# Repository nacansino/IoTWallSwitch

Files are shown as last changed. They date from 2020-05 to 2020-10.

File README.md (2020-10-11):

# IoTWallSwitch
An open-source IoT Wall Switch based on ESP device. I based this project on Xoseperez's [espurna-board project](https://github.com/xoseperez/espurna-board).

I aim this project to be a foundation of many small projects that ran on tap power supply.

## Block Diagram
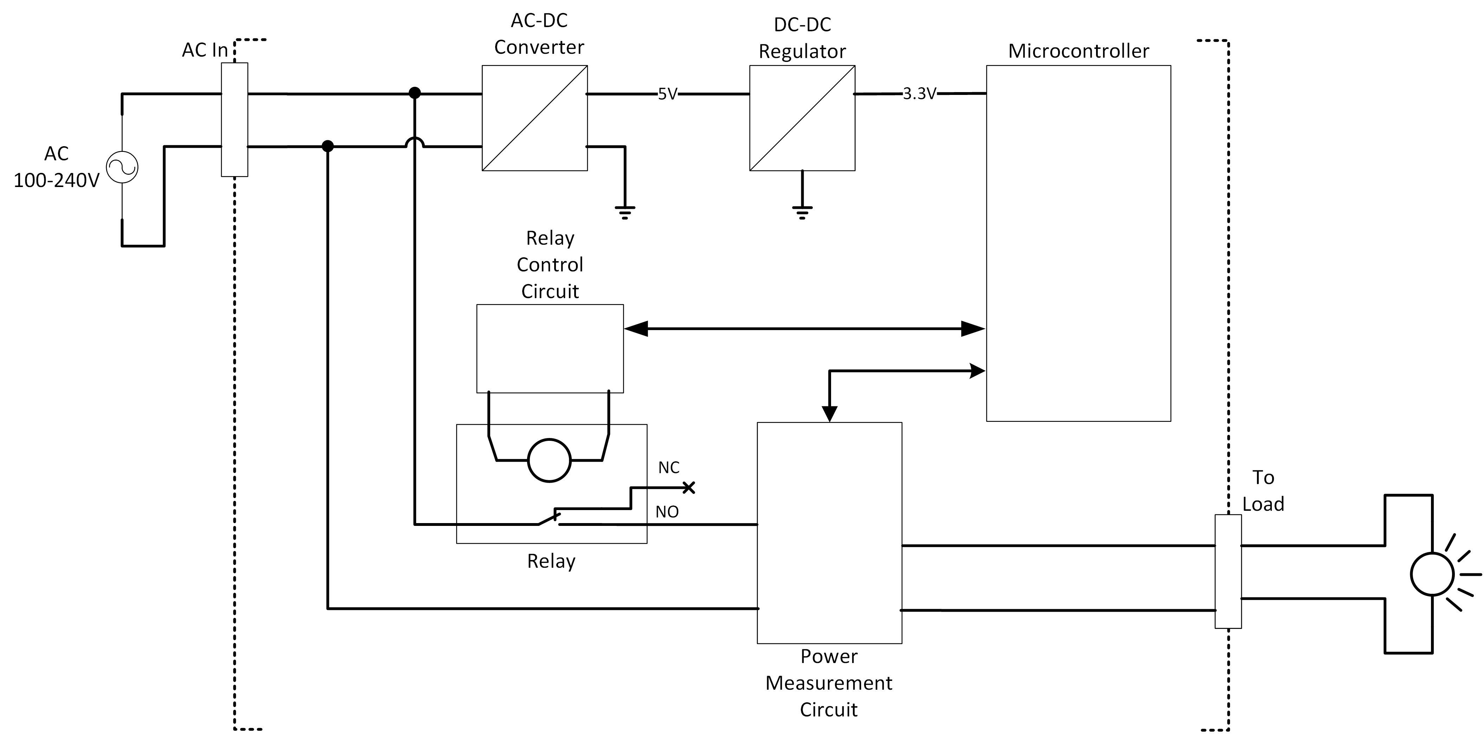
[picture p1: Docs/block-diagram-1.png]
Block Diagram


## Primary Functionalities (User perspective):
1. Act as an on/off switch of an alternating or direct current load; the method of switching shall be done via physical access (e.g. button, capacitive touch) or via wirelessly (web interface, telnet, etc.)
2. Has the capability to measure the power consumed by the load, and to report it to an external entity (cloud, local household server).
3. Support more than one wireless protocol for redundancy
4. Has the capability to update functionality after deployment without physical access (over-the-air or OTA updates).

## Tech Stack
- Schematic and Layout: KiCAD
- Toolchain: TBA, currently thinking of building over ESP-IDF
- Unit Testing: CppUTest

## Applications:
- Generic Smart Switch for any load below 10A
- Household and industrial lighting
- Small motors/fans/pumps
- Desktop/Laptop Charger
- Television
- Speakers

## 3D Preview

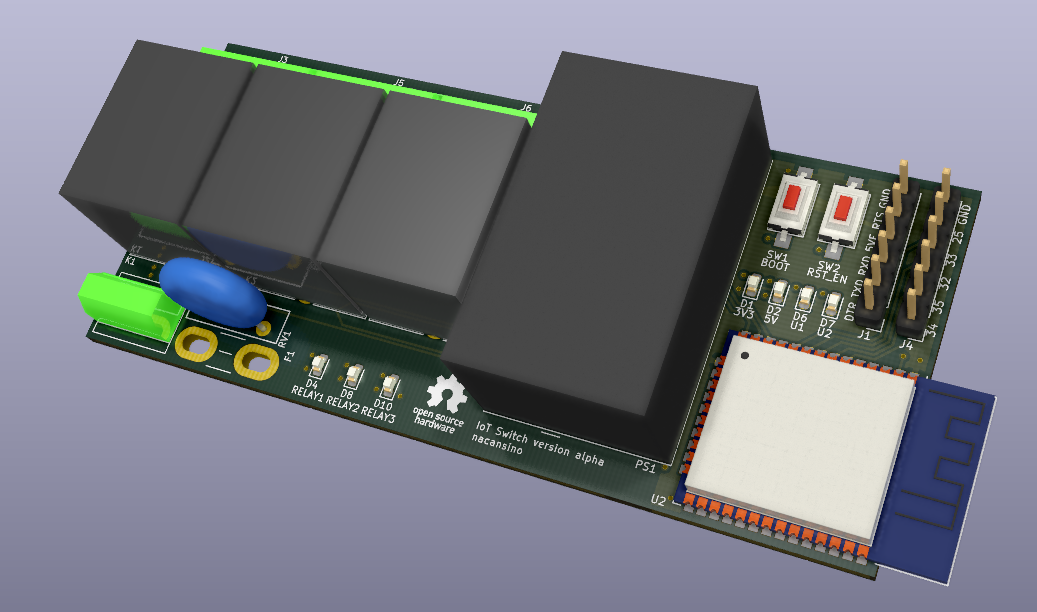
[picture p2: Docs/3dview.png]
3dView


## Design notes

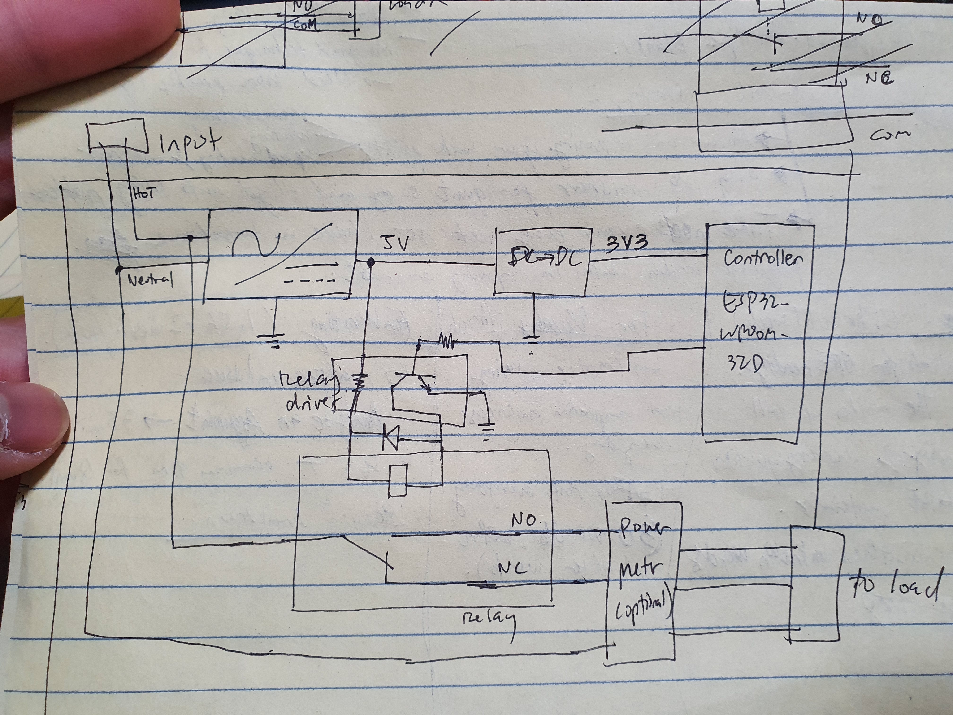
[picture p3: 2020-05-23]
Docs/img/scratch_paper_design_05_17_2020.jpg

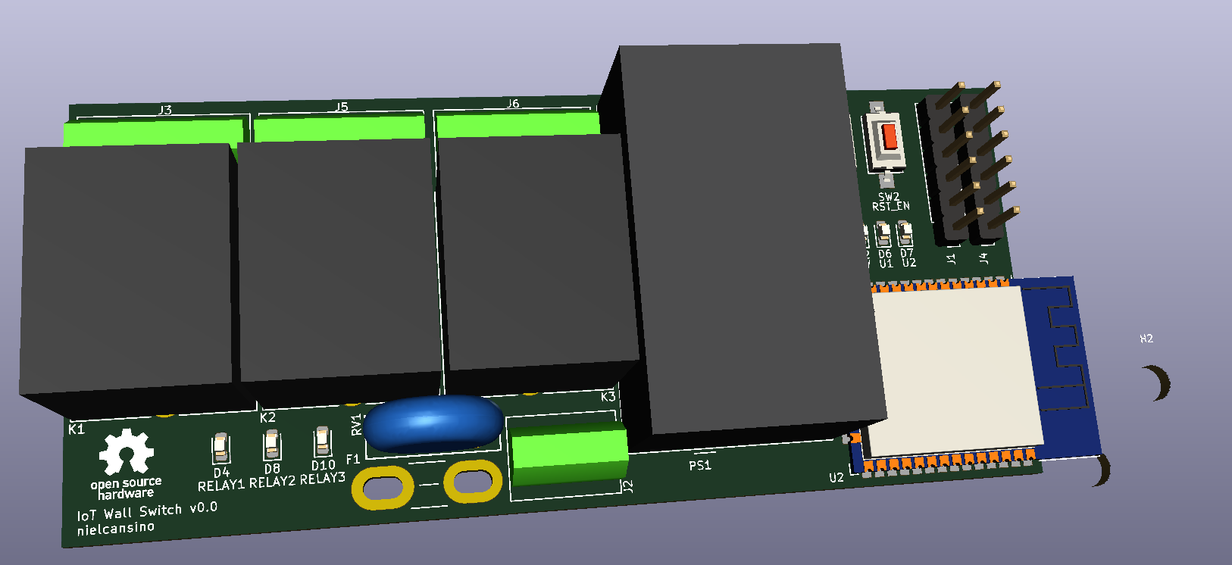
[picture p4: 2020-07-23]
Docs/img/layout_wip2.PNG

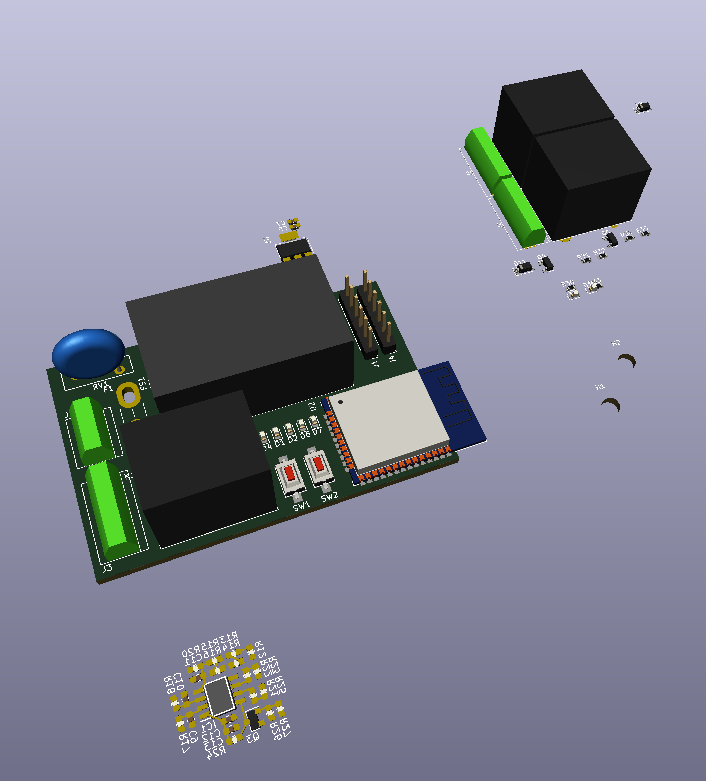
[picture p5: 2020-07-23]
Docs/img/layout_wip.PNG

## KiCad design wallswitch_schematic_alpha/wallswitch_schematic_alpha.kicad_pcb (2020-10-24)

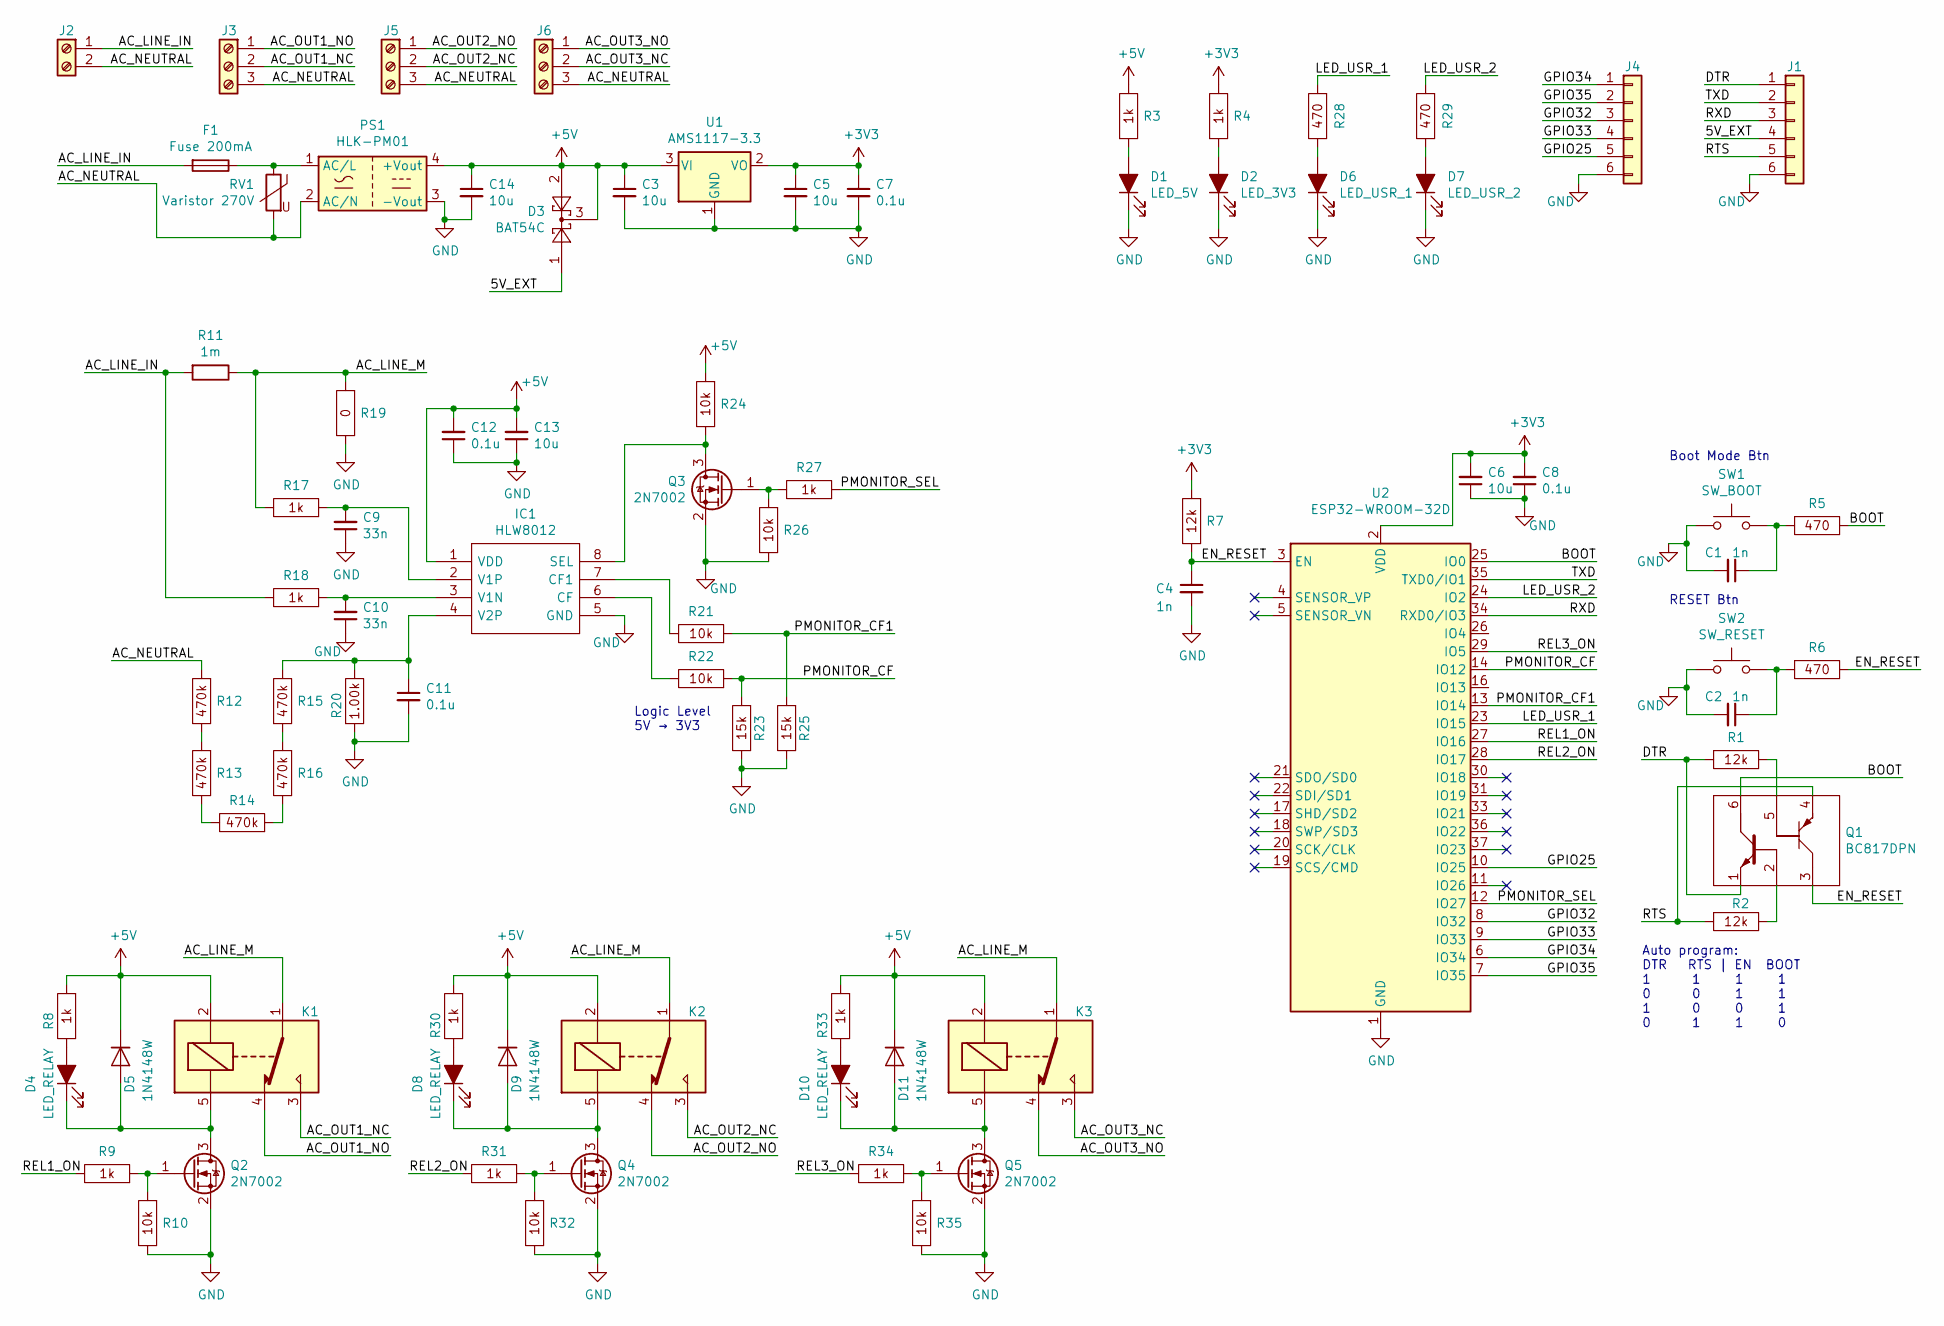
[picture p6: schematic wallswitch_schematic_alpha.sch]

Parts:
C1, C2, C4: 1n; C_0603_1608Metric
C3, C5, C6, C13, C14: 10u; C_0603_1608Metric
C7, C8, C11, C12: 0.1u; C_0603_1608Metric
C9, C10: 33n; C_0603_1608Metric
D1: LED_5V; LED_0603_1608Metric
D2: LED_3V3; LED_0603_1608Metric
D3: BAT54C; SOT-23
D4, D8, D10: LED_RELAY; LED_0603_1608Metric
D5, D9, D11: 1N4148W; D_SOD-123
D6: LED_USR_1; LED_0603_1608Metric
D7: LED_USR_2; LED_0603_1608Metric
F1: Fuse 200mA; Fuse_Blade_Mini_directSolder
IC1: HLW8012; SOIC127P600X170-8N; Manufacturer_Part_Number HLW8012
J1, J4: Conn_01x06; PinHeader_1x06_P2.54mm_Vertical
J2: Screw_Terminal_01x02; TerminalBlock_bornier-2_P5.08mm
J3, J5, J6: Screw_Terminal_01x03; TerminalBlock_bornier-3_P5.08mm
K1, K2, K3: SANYOU_SRD_Form_C; Relay_SPDT_SANYOU_SRD_Series_Form_C
PS1: HLK-PM01; Converter_ACDC_HiLink_HLK-PMxx
Q1: BC817DPN; SOT95P275X110-6N; Manufacturer_Part_Number BC817DPN; Mouser Part Number N/A
Q2, Q3, Q4, Q5: 2N7002; SOT-23
R1, R2, R7: R_12k_±5%_1608m; R_0603_1608Metric; Power Rating 0.1W; Tolerance ±5%
R3, R4, R8, R9, R17, R18, R27, R30, R31, R33, R34: R_1k_±5%_1608m; R_0603_1608Metric; Power Rating 0.125W; Tolerance ±5%
R5, R6, R28, R29: R_470_±5%_1608m; R_0603_1608Metric; Power Rating 0.125W; Tolerance ±5%
R10, R21, R22, R24, R26, R32, R35: R_10k_±5%_1608m; R_0603_1608Metric; Power Rating 0.1W; Tolerance ±5%
R11: 1m; R_2512_6332Metric_Pad1.52x3.35mm_HandSolder
R12, R13, R14, R15, R16: R_470k_±1%_1608m; R_0603_1608Metric; Power Rating 0.1W; Tolerance ±1%
R19: R_0_―_1608m; R_0603_1608Metric; Power Rating 1A; Tolerance ―
R20: R_1.00k_±1%_1608m; R_0603_1608Metric; Power Rating 0.125W; Tolerance ±1%
R23, R25: R_15k_±5%_1608m; R_0603_1608Metric; Power Rating 0.1W; Tolerance ±5%
RV1: Varistor 270V; RV_Disc_D12mm_W3.9mm_P7.5mm
SW1: SW_BOOT; SW_SPST_CK_RS282G05A3
SW2: SW_RESET; SW_SPST_CK_RS282G05A3
U1: AMS1117-3.3; SOT-223-3_TabPin2
U2: ESP32-WROOM-32D; ESP32-WROOM-32

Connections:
+3V3: C5.1, C6.2, C7.1, C8.2, R4.2, R7.1, U1.2 (VO), U2.2 (VDD)
+5V: C3.1, C12.2, C13.2, C14.1, D3.2, D3.3, D5.1 (K), D9.1 (K), D11.1 (K), IC1.1 (VDD), K1.2, K2.2, K3.2, PS1.4 (+Vout), R3.2, R8.1, R24.1, R30.1, R33.1, U1.3 (VI)
/5V_EXT: D3.1, J1.4
/AC_LINE_IN: F1.2, J2.1, R11.2, R18.2
/AC_LINE_M: K1.1, K2.1, K3.1, R11.1, R17.2, R19.1
/AC_NEUTRAL: J2.2, J3.3, J5.3, J6.3, PS1.2 (AC/N), R12.1, RV1.2
/AC_OUT1_NC: J3.2, K1.3
/AC_OUT1_NO: J3.1, K1.4
/AC_OUT2_NC: J5.2, K2.3
/AC_OUT2_NO: J5.1, K2.4
/AC_OUT3_NC: J6.2, K3.3
/AC_OUT3_NO: J6.1, K3.4
/BOOT: Q1.6, R5.2, U2.25 (IO0)
/DTR: J1.1, Q1.1, R1.1
/EN_RESET: C4.1, Q1.3, R6.2, R7.2, U2.3 (EN)
/GPIO25: J4.5, U2.10 (IO25)
/GPIO32: J4.3, U2.8 (IO32)
/GPIO33: J4.4, U2.9 (IO33)
/GPIO34: J4.1, U2.6 (IO34)
/GPIO35: J4.2, U2.7 (IO35)
/LED_USR_1: R28.1, U2.23 (IO15)
/LED_USR_2: R29.1, U2.24 (IO2)
/PMONITOR_CF: R22.1, R23.1, U2.14 (IO12)
/PMONITOR_CF1: R21.1, R25.1, U2.13 (IO14)
/PMONITOR_SEL: R27.1, U2.12 (IO27)
/REL1_ON: R9.2, U2.27 (IO16)
/REL2_ON: R31.2, U2.28 (IO17)
/REL3_ON: R34.2, U2.29 (IO5)
/RTS: J1.5, Q1.4, R2.1
/RXD: J1.3, U2.34 (RXD0/IO3)
/TXD: J1.2, U2.35 (TXD0/IO1)
GND: C1.2, C2.2, C3.2, C4.2, C5.2, C6.1, C7.2, C8.1, C9.1, C10.1, C11.2, C12.1, C13.1, C14.2, D1.1 (K), D2.1 (K), D6.1 (K), D7.1 (K), IC1.5 (GND), J1.6, J4.6, PS1.3 (-Vout), Q2.2 (S), Q3.2 (S), Q4.2 (S), Q5.2 (S), R10.2, R19.2, R20.1, R23.2, R25.2, R26.2, R32.2, R35.2, SW1.1, SW2.1, U1.1 (GND), U2.1 (GND), U2.15 (GND), U2.38 (GND), U2.39 (GND)
unnamed: C1.1, R5.1, SW1.2
unnamed: C2.1, R6.1, SW2.2
unnamed: C9.2, IC1.2 (V1P), R17.1
unnamed: C10.2, IC1.3 (V1N), R18.1
unnamed: C11.1, IC1.4 (V2P), R15.2, R20.2
unnamed: D1.2 (A), R3.1
unnamed: D2.2 (A), R4.1
unnamed: D4.1 (K), D5.2 (A), K1.5, Q2.3 (D)
unnamed: D4.2 (A), R8.2
unnamed: D6.2 (A), R28.2
unnamed: D7.2 (A), R29.2
unnamed: D8.1 (K), D9.2 (A), K2.5, Q4.3 (D)
unnamed: D8.2 (A), R30.2
unnamed: D10.1 (K), D11.2 (A), K3.5, Q5.3 (D)
unnamed: D10.2 (A), R33.2
unnamed: F1.1, PS1.1 (AC/L), RV1.1
unnamed: IC1.6 (CF), R22.2
unnamed: IC1.7 (CF1), R21.2
unnamed: IC1.8 (SEL), Q3.3 (D), R24.2
unnamed: Q1.2, R2.2
unnamed: Q1.5, R1.2
unnamed: Q2.1 (G), R9.1, R10.1
unnamed: Q3.1 (G), R26.1, R27.2
unnamed: Q4.1 (G), R31.1, R32.1
unnamed: Q5.1 (G), R34.1, R35.1
unnamed: R12.2, R13.1
unnamed: R13.2, R14.2
unnamed: R14.1, R16.2
unnamed: R15.1, R16.1

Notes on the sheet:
Logic Level 5V → 3V3
Auto program: DTR RTS | EN BOOT 1 1 1 1 0 0 1 1 1 0 0 1 0 1 1 0
Boot Mode Btn
RESET Btn

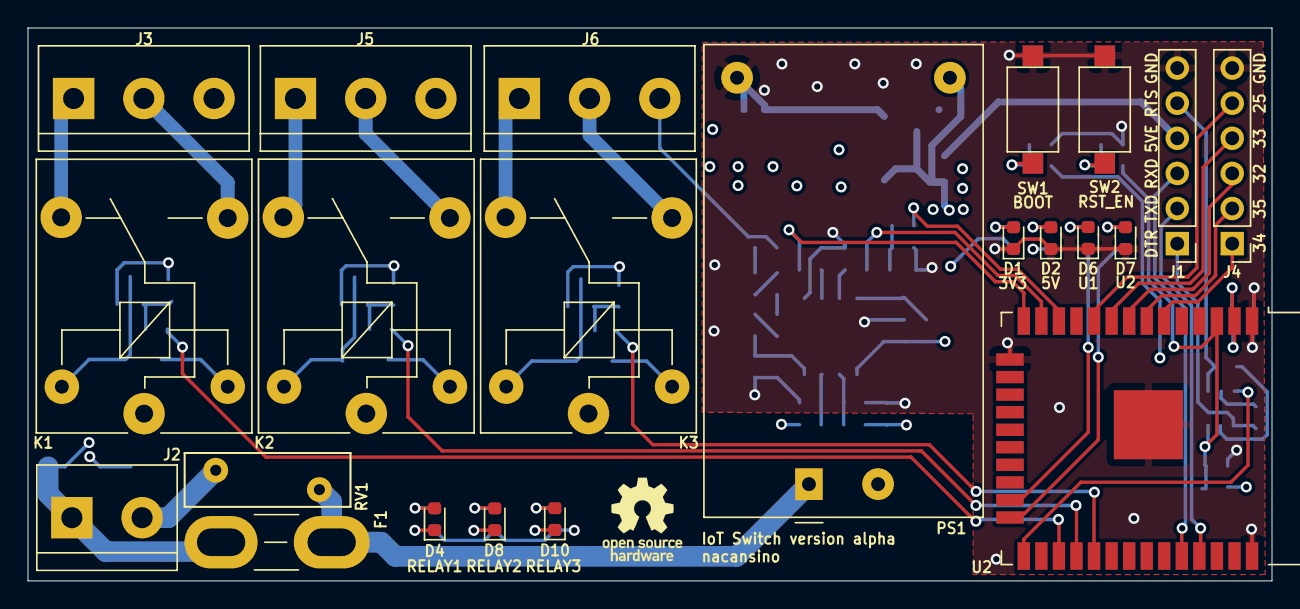
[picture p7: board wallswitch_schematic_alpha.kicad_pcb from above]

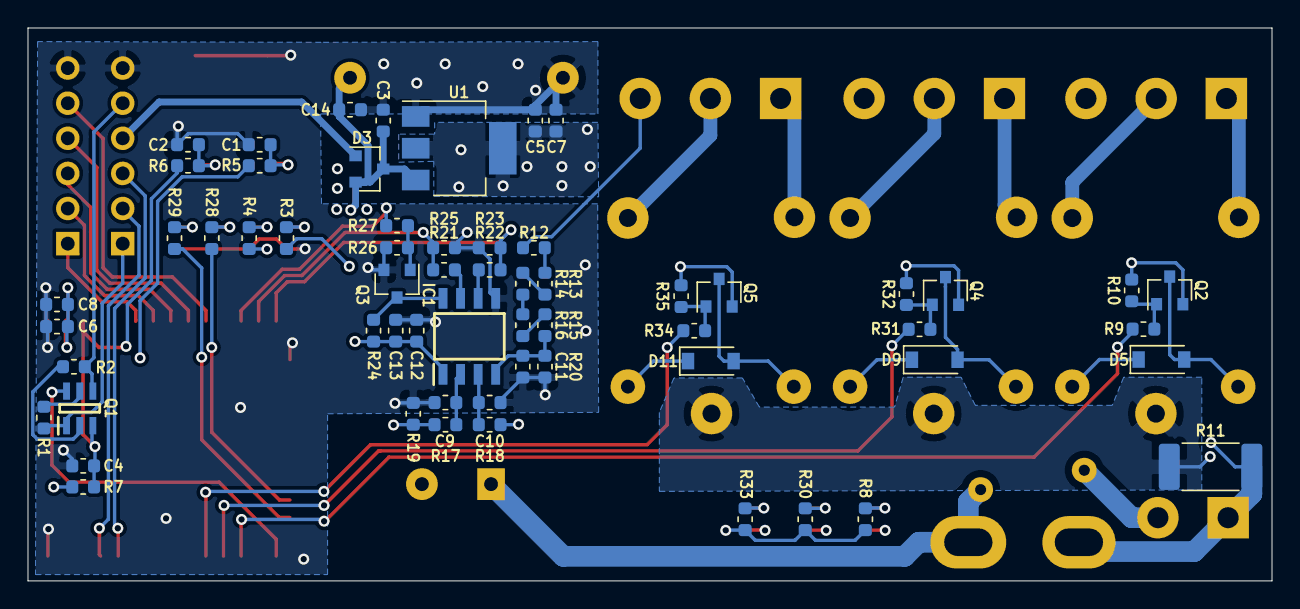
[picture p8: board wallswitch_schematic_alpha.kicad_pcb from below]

Board: 4 copper layers, 90.0 x 40.0 mm, 82 parts (60 on the bottom side), 61 nets.

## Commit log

2020-05-24 added circuit
    [wallswitch_schematic_alpha.kicad_pcb, wallswitch_schematic_alpha.sch]
2020-05-24 added wall switch
2020-05-24 schematic - added components
    [wallswitch_schematic_alpha.sch]
2020-05-24 added peripheral circuit (50%)
    [wallswitch_schematic_alpha.sch]
2020-05-31 added esp32 general datasheet
2020-05-31 updated peripheral circuits
    [wallswitch_schematic_alpha.sch]
2020-06-13 added components
    [wallswitch_schematic_alpha.sch]
2020-06-28 added *.kicad_pcb-bak to ignore list
2020-06-28 modification of some components to use new XLAB footprint
    [wallswitch_schematic_alpha.kicad_pcb, wallswitch_schematic_alpha.sch]
2020-06-28 1. Attached appropriate footprint to connectors 2. TODO: Capacitors and varistor
    [wallswitch_schematic_alpha.kicad_pcb, wallswitch_schematic_alpha.sch]
2020-07-19 progress for layout
    [wallswitch_schematic_alpha.kicad_pcb, wallswitch_schematic_alpha.sch]
2020-10-11 finished artwork
    [wallswitch_schematic_alpha.kicad_pcb]
2020-10-11 added 3d picture to readme
    [wallswitch_schematic_alpha.kicad_pcb]
2020-10-24 modification to generate gerber files
    [wallswitch_schematic_alpha-B_Cu.gbr, wallswitch_schematic_alpha-B_Mask.gbr, wallswitch_schematic_alpha-B_Paste.gbr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]
